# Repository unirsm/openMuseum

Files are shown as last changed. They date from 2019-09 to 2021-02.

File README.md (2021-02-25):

# openMuseum

## 1.0 Il progetto

### 1.1 Descrizione generale del progetto

Il Progetto di ricerca triennale “Nuovi sistemi integrativi per la fruizione del percorso espositivo della Casa Museo“ ha coinvolto in un programma di progettazione partecipata un gruppo di ricerca dell’area Exhibit e Interaction Design dell’Università delgi Studi della Repubblica di San Marino e le otto Istituzioni del Coordinamento delle Case Museo dei Poeti e degli Scrittori di Romagna (Protocollo di intesa sottoscritto dall’Università e dal Comune di Forlì, in qualità di Comune capofila del Coordinamento delle Case Museo dei Poeti e degli Scrittori di Romagna in data 18 luglio 2017).

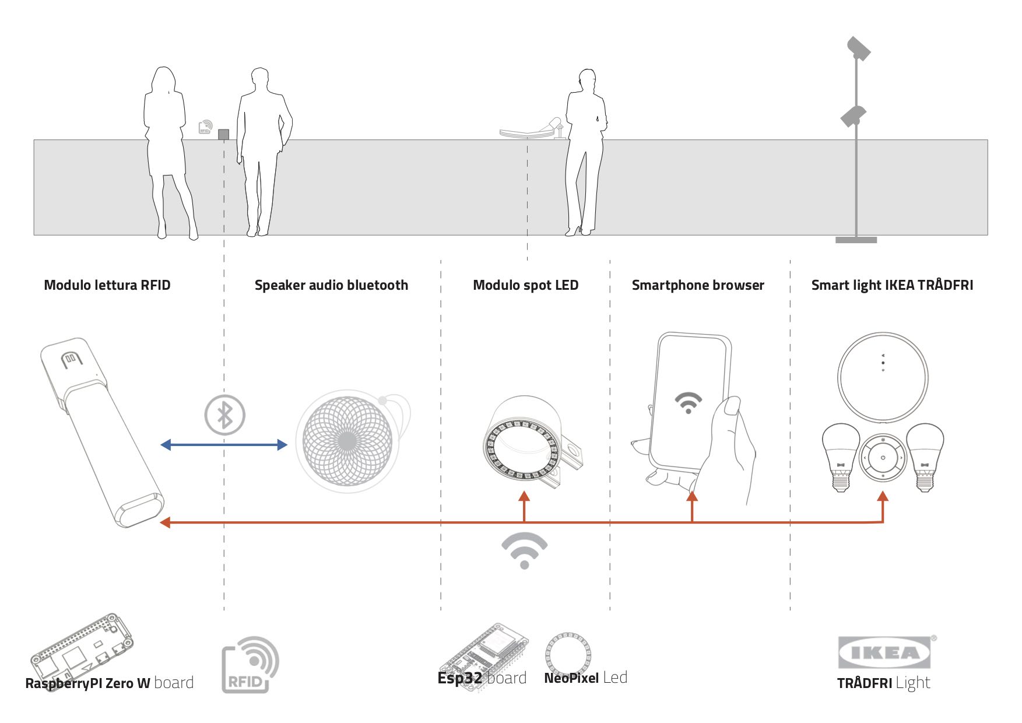
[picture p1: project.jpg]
Schema del progetto del sistema interattivo


### 1.2	Componenti hardware progettati

- [Reader RFID](reader/)
- [Spot Light neopixel](spotNeopixel/)
- [Server](server/)

### 1.3 Gruppo di lavoro progetto

Alessandra Bosco, Elena La Maida, Emanuele Lumini, Mirco Piccin e Michele Zannoni

## 2.0 Analisi preliminare e presupposti di progetto

### 2.1 Contesto

 - Case museo eterogenee con tipologie molto diverse di percorsi
   espositivi.
- Spazi liberi vuoti o stanze arredate.

### 2.2 Vincoli delle case museo

Necessità di un intervento non invasivo
- Impossibilità di fare interventi strutturali in diverse sale che alterino l’allestimento storico
- Allaccio alla rete elettrica molto problematico e troppo invasivo per alcuni contesti espositivi
- Non caricare dal punto di vista elettrico le strutture espositive
- Necessità dell’uso di una batteria e di un processo di ricarica semplice
- Sistema di ricarica della batteria certificato
- Personale eterogeneo e non preparato che può essere formato
- Problemi di connessione delle case
- Costo molto basso dell’oggetto interattivo
- Facilità e flessibilità d’uso

### 2.3	Presupposti

- Evitare l’inserimento di elementi estranei alle case museo evitando schermi e sistemi visivi permanenti
- Sviluppo di un sistema aperto e implementabile dagli operatori
- Dimensione contenuta degli oggetti
- Visibilità degli oggetti

### 2.4	Obiettivi principali

Gestione della presenza del visitatore nello spazio e attivazione di processi di interazione con contenuti audio e video.
- Permettere la contestualizzazione di un audio narrativo localizzato attivabile da un visitatore o da una guida.
- Gestire luci all’interno dello spazio per sottolineare singoli elementi.
- Sviluppare un progetto aperto e opensource che gli operatori delle case museo possano gestire in autonomia e modificare in futuro.
- Attivazione di contenuti specifici su smartphone in relazione alla prossimità.
- Piattaforma online per la gestione dei sistemi interattivi delle case
- Raccolta da remoto dei dati delle visite
- Strumenti di analisi dei dati dei visitatori all’interno delle case museo.
- Gestione degli elementi interattivi da remoto
- Gestione dinamica di un videoproiettore connesso alla rete elettrica. Struttura permanente da sviluppare in via prototipale ma non applicabile al budget del progetto.
- Gestione del mapping in spazi vuoti in maniera dinamica.

## 3.0 License

Attribution-NonCommercial 4.0 International (CC BY-NC 4.0)
the  [license](https://creativecommons.org/licenses/by-nc/4.0/legalcode). [Disclaimer](https://creativecommons.org/licenses/by-nc/4.0/#).

Share — copy and redistribute the material in any medium or format
Adapt — remix, transform, and build upon the material
The licensor cannot revoke these freedoms as long as you follow the license terms.
Authors: Alessandra Bosco, Elena La Maida, Emanuele Lumini, Mirco Piccin e Michele Zannoni

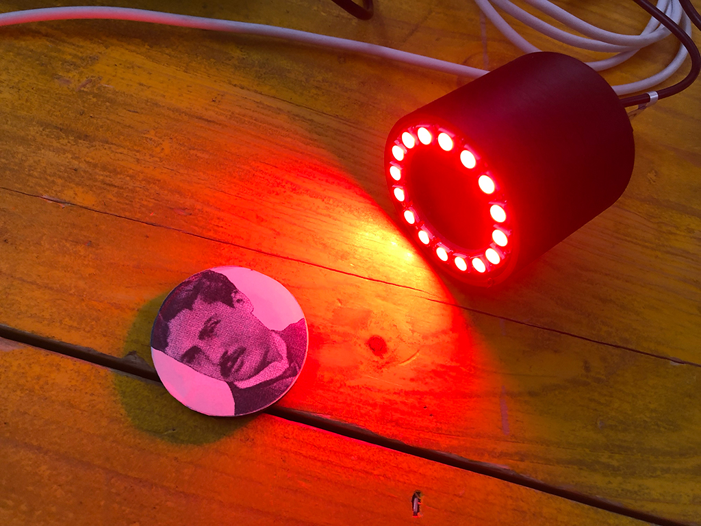
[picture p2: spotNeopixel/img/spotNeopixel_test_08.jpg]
Spot Light neopixel Prototipo


Fig. 1 Lo spot realizzato per la sperimentazione

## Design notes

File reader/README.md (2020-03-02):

# Modulo lettore RFID portatile

Il lettore portatile funziona leggendo con  antenna  RC522 i tag RFID posizionati nello spazio espositivo. Il sistema è costituito da una Raspberry PI zero W con installato Node-Red e Mosquitto.
Il lettore può essere connesso a qualsiasi sistema di riproduzione audio Bluetooth (Speaker, Cuffie e sistemi di diffusione audio permanenti).

## Password e user delle ISO e del reader
La password di default dell'utente "pi" dell'ISO è "password"

La password di default di Node-Red dell'utente "admin" è "password"

La password di default del sistema di gestione dei contenuti multimediali dell'utente "admin" è "password"

[Download ISO 20190929 v.07a](https://www.dropbox.com/s/mdmm8pqs013waee/20190929_Iso_base_CCM.img.zip?dl=0)

[Last Node-Red flow](node-red/flows_casamuseorpi.json)

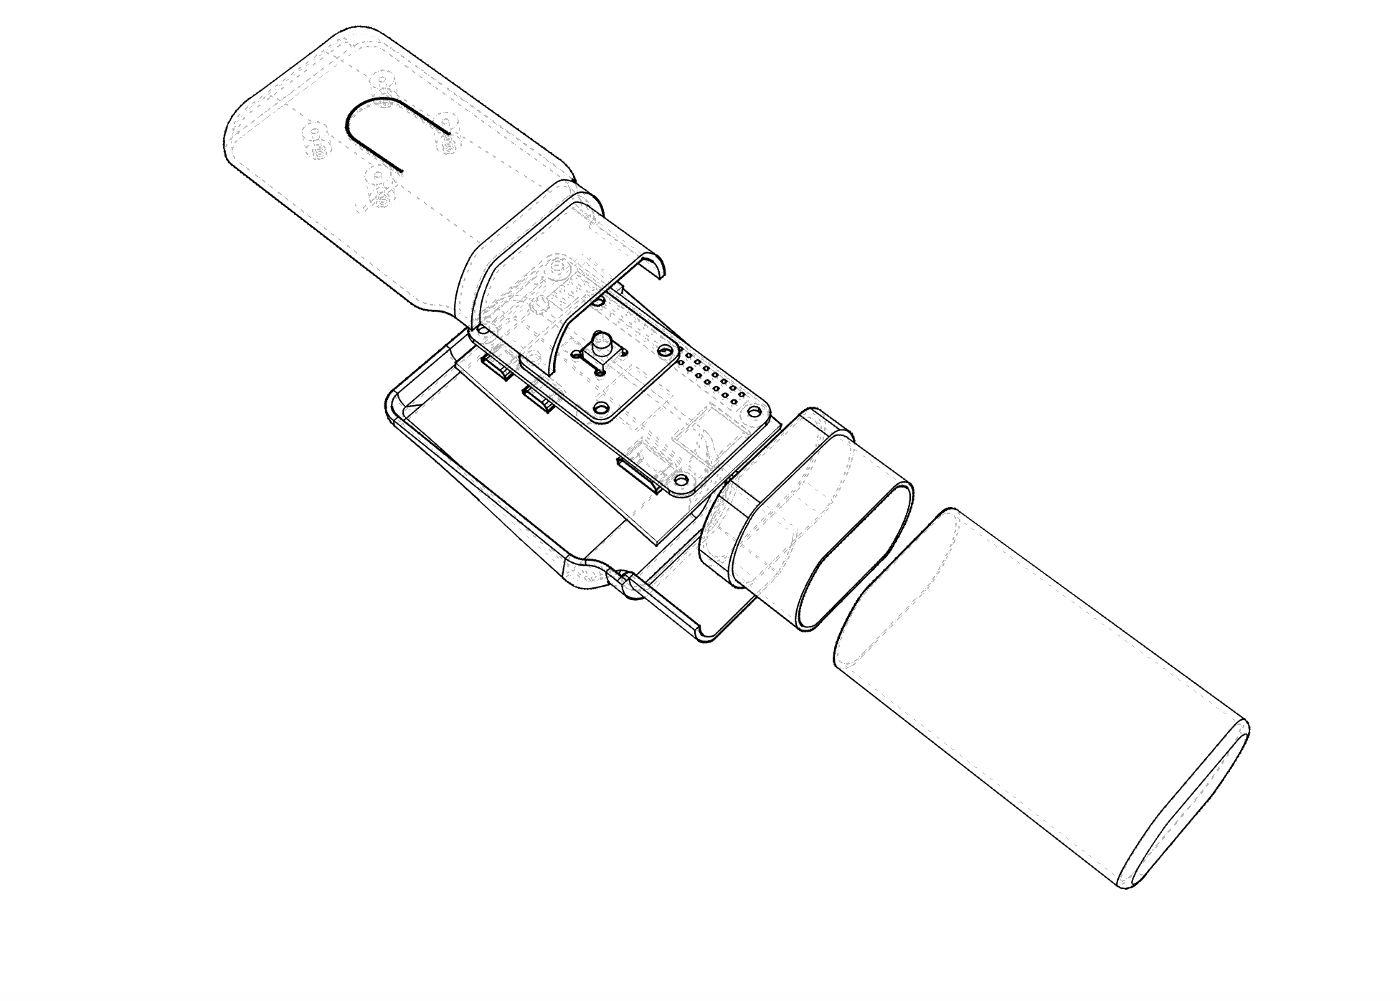
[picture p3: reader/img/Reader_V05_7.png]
Reader 3D printing model 5


## Procedura di aggiornamento

- 1	Caricamento del FLOW aggiornato
- 1.1	Collegarsi in SFTP al device
- 1.2	Caricare il file flows_casamuseorpi.json nella cartella /home/pi/.node-red/ (Attivare la visualizzazione dei file nascosti)
- 1.3	Caricare il vostro file logo.png nella cartella /home/pi/media/
- 1.4	Riavviare il device

## Dimensione componenti

- Raspberry PI zero W: 			32x68x6 mm

- antenna rfid RC522: 			39x60x6 mm
s
- powerbank: 				94x24x23 mm

- pulsante switch 			6x6x7 mm
- Bluetooth Speaker esterno

## Hardware

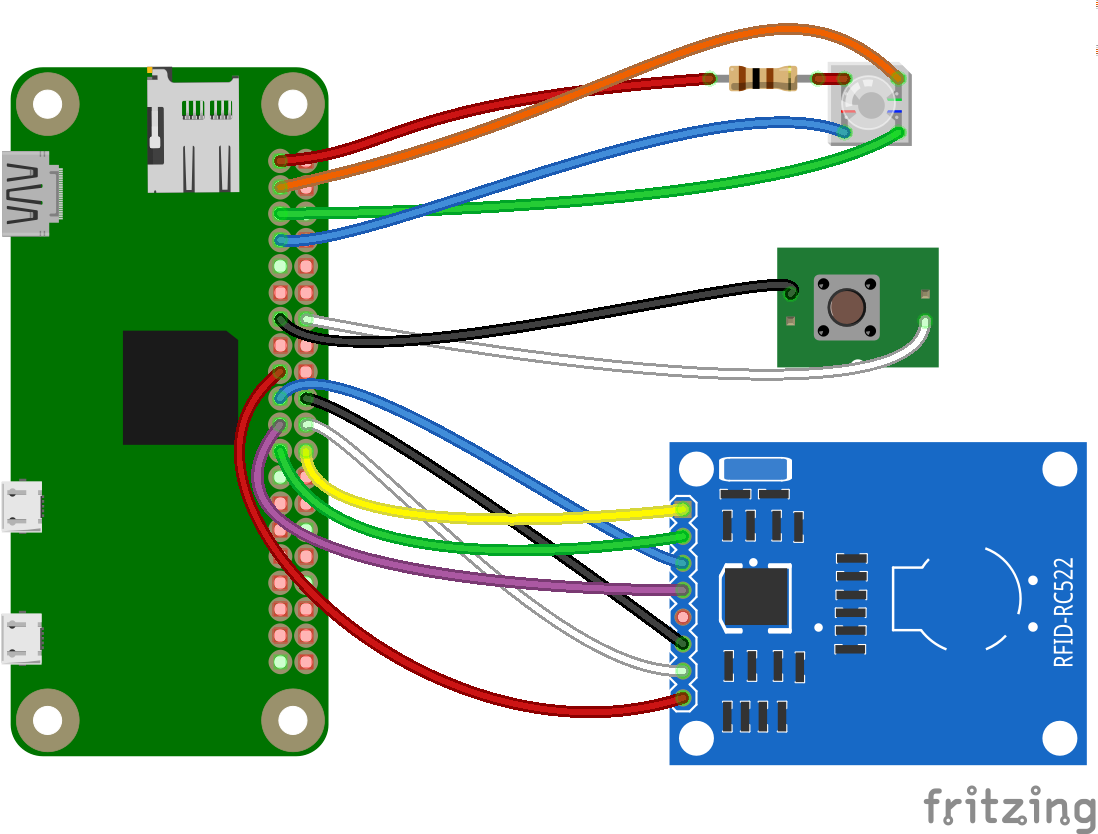
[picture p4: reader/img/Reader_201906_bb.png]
Reader hardware connections

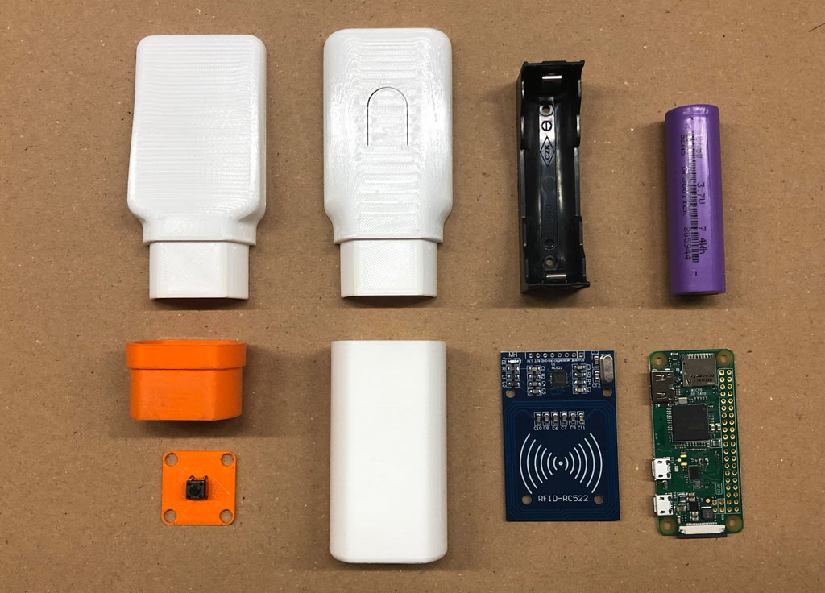
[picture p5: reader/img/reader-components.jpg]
Hardware components


## The 3d printing model

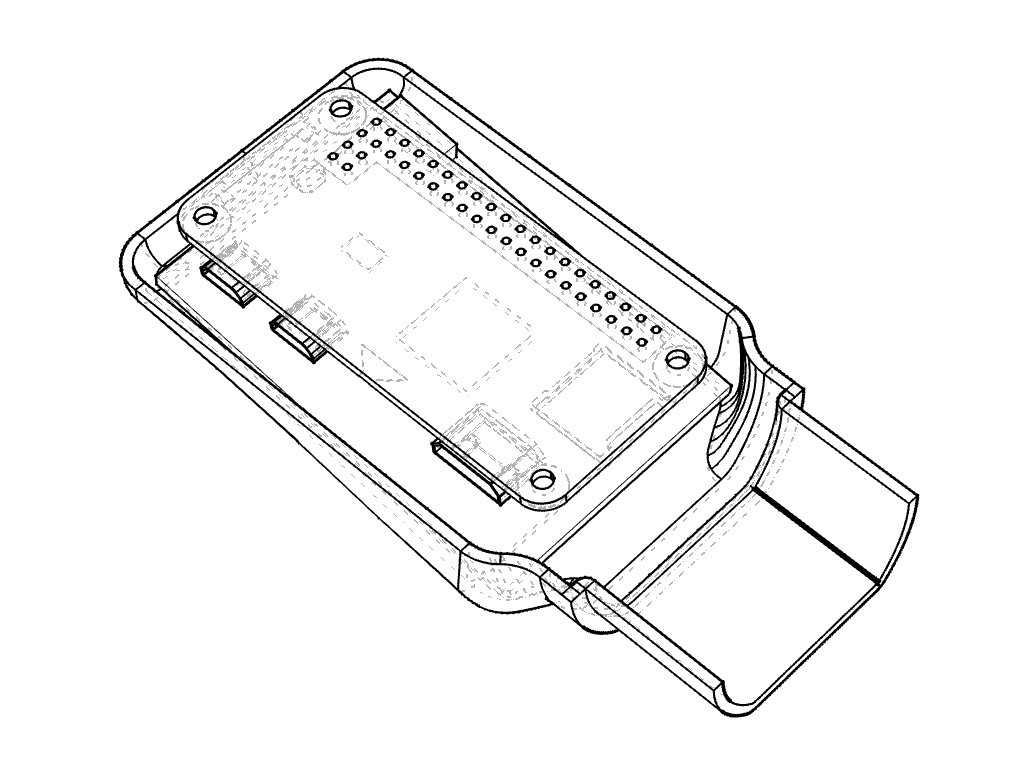
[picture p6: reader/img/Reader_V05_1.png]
Reader picture 1 model 5

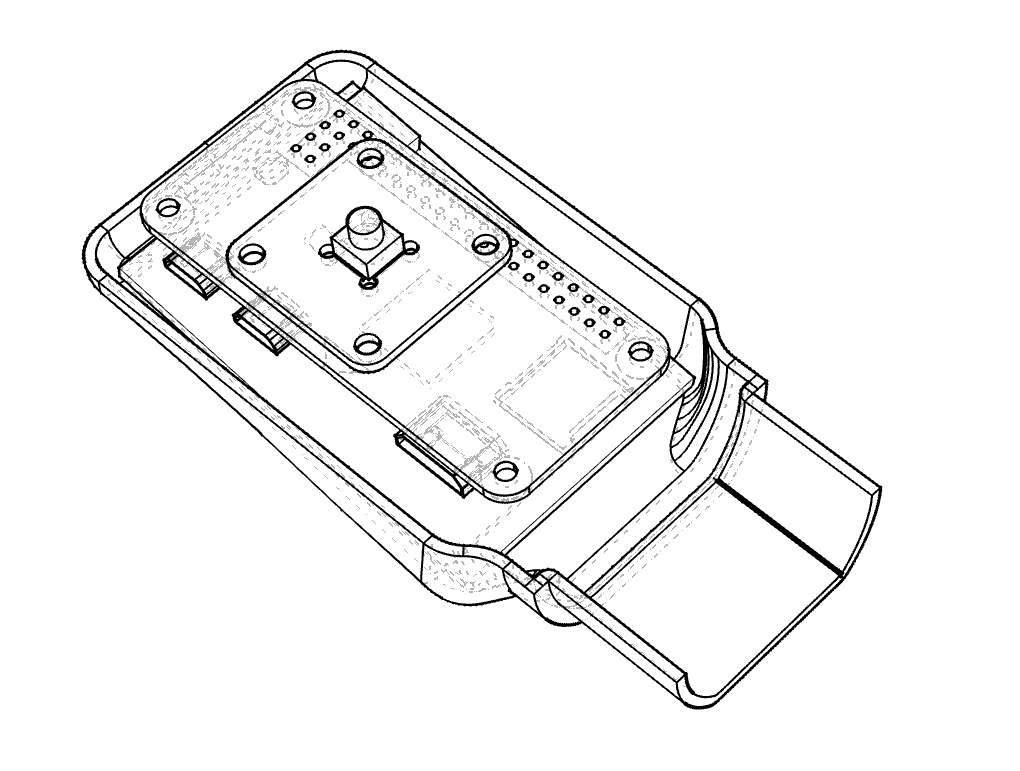
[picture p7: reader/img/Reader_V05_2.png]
Reader picture 2 model 5

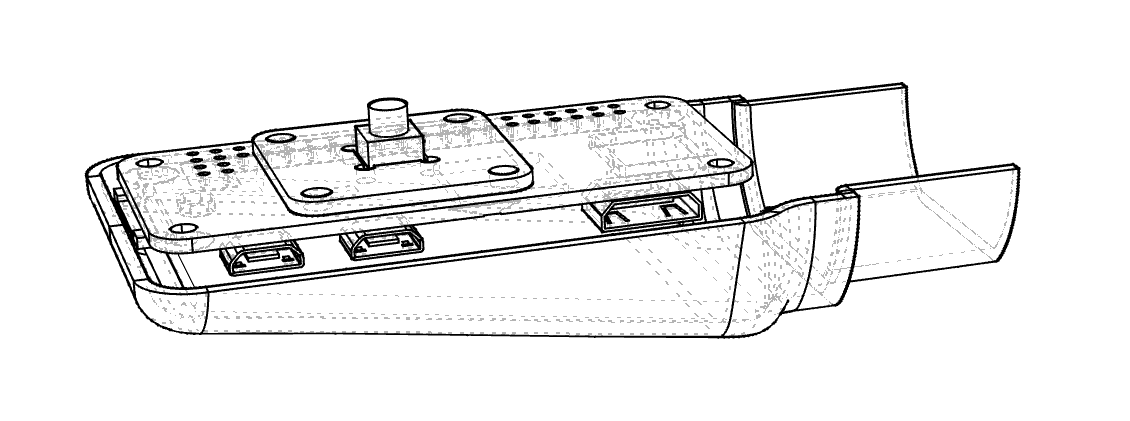
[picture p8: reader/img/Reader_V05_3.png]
Reader picture 3 model 5

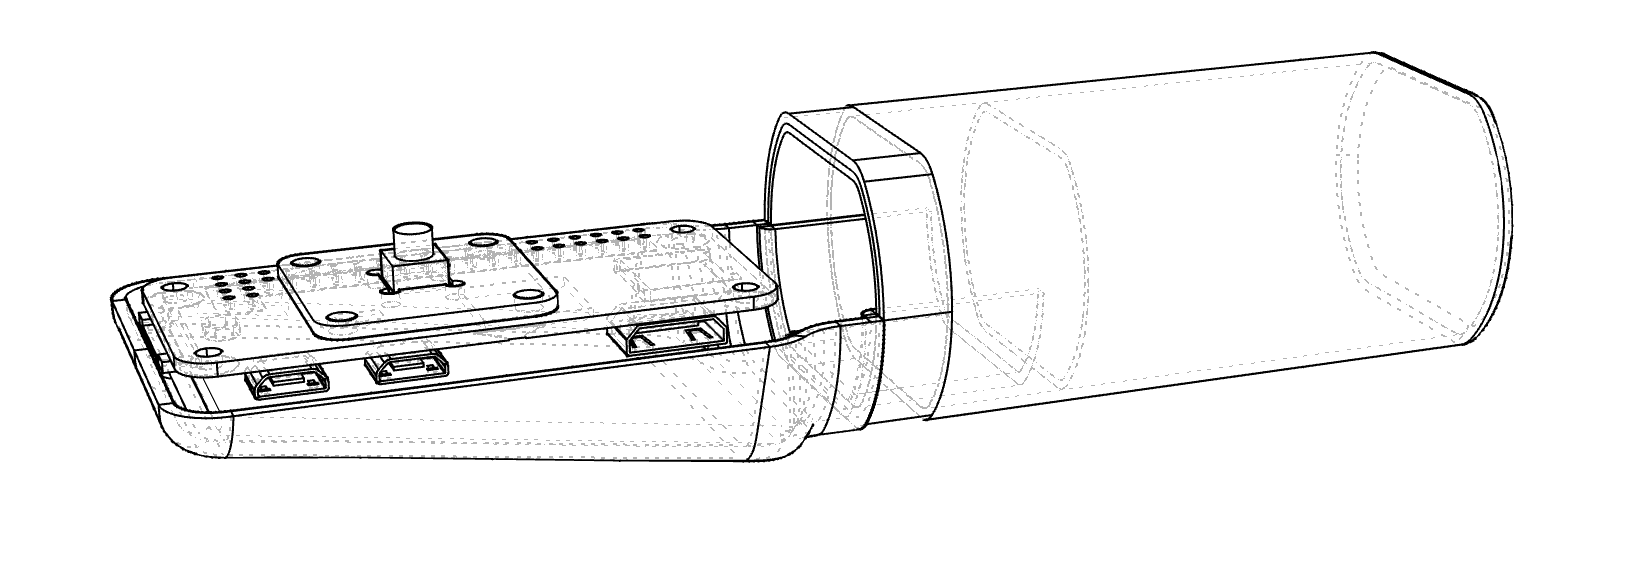
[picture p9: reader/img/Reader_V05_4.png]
Reader picture 4 model 5

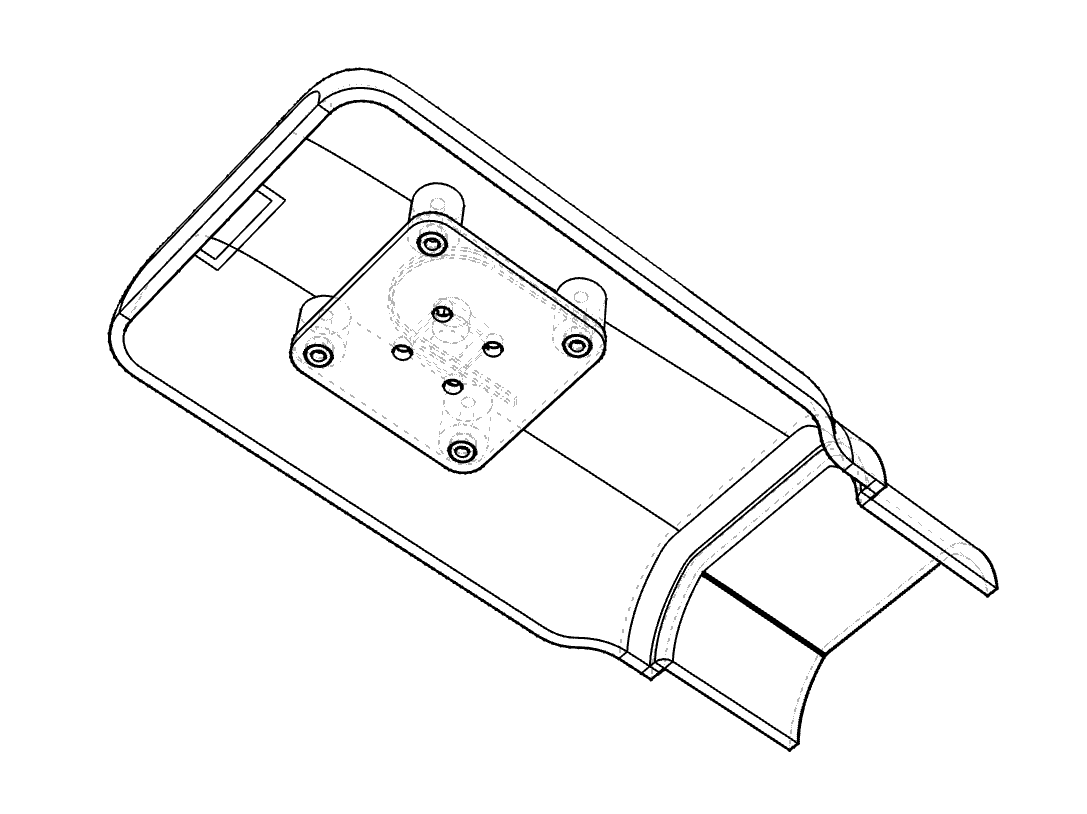
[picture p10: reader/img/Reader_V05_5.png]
Reader picture 5 model 5

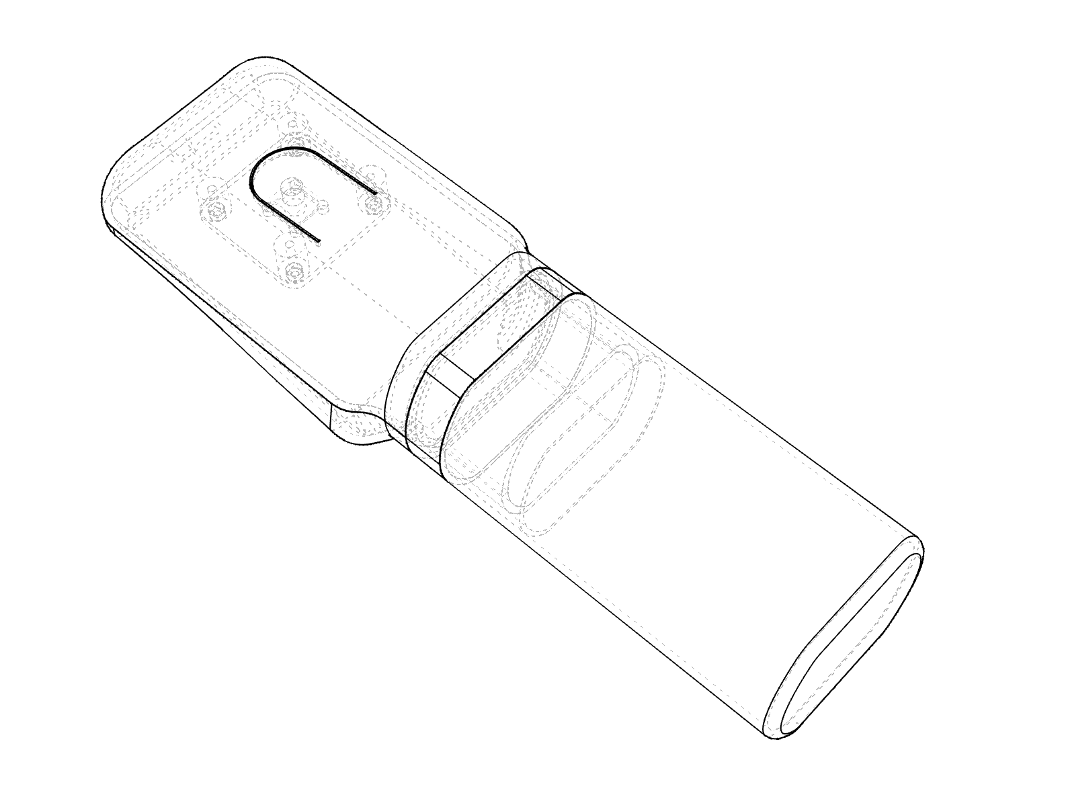
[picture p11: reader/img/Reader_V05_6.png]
Reader picture 6 model 5


## The prototypes

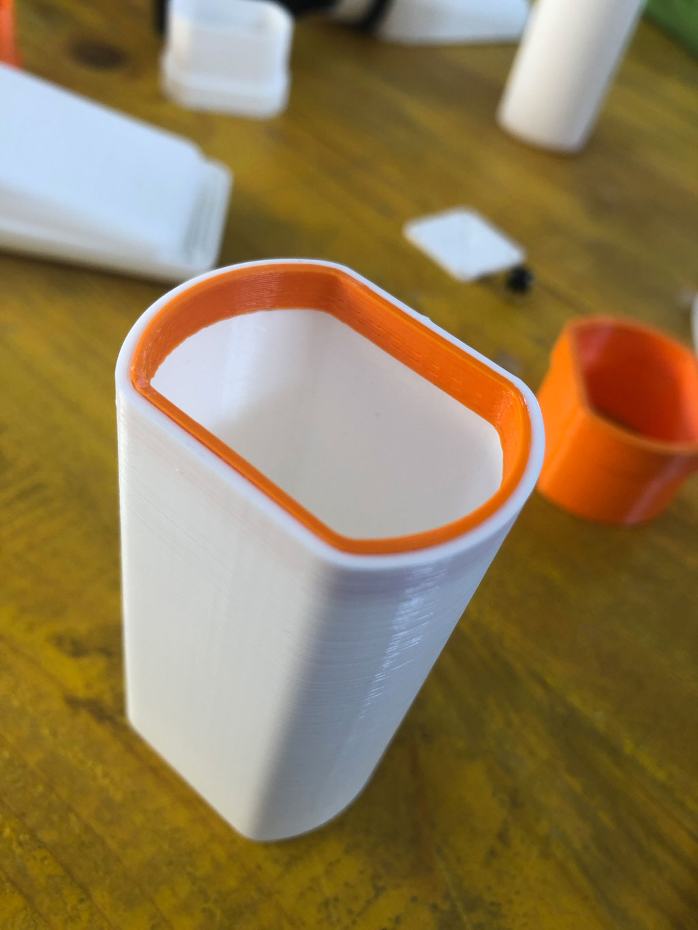
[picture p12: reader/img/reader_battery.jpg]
Reader picture 6 model 5

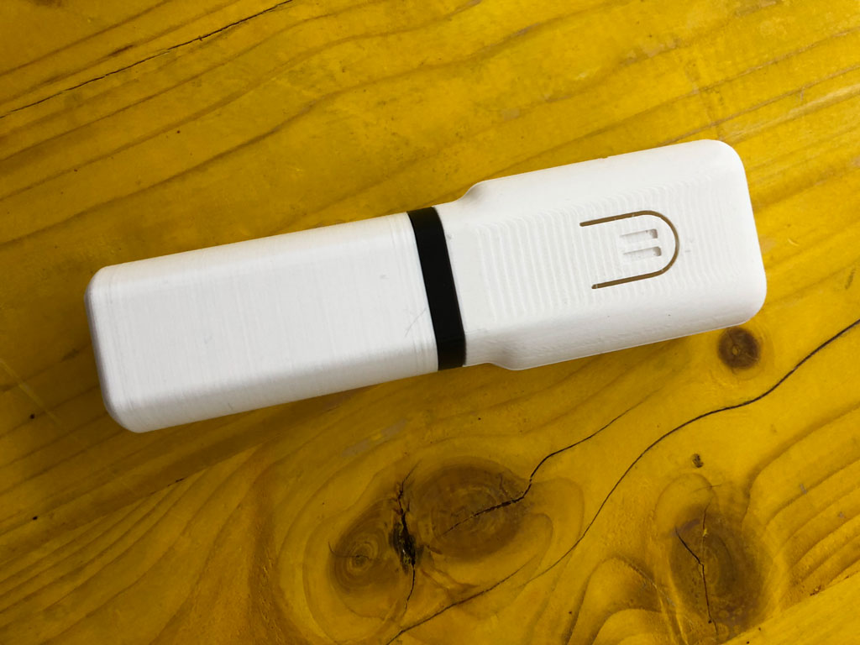
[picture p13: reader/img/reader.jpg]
Reader picture 6 model 5

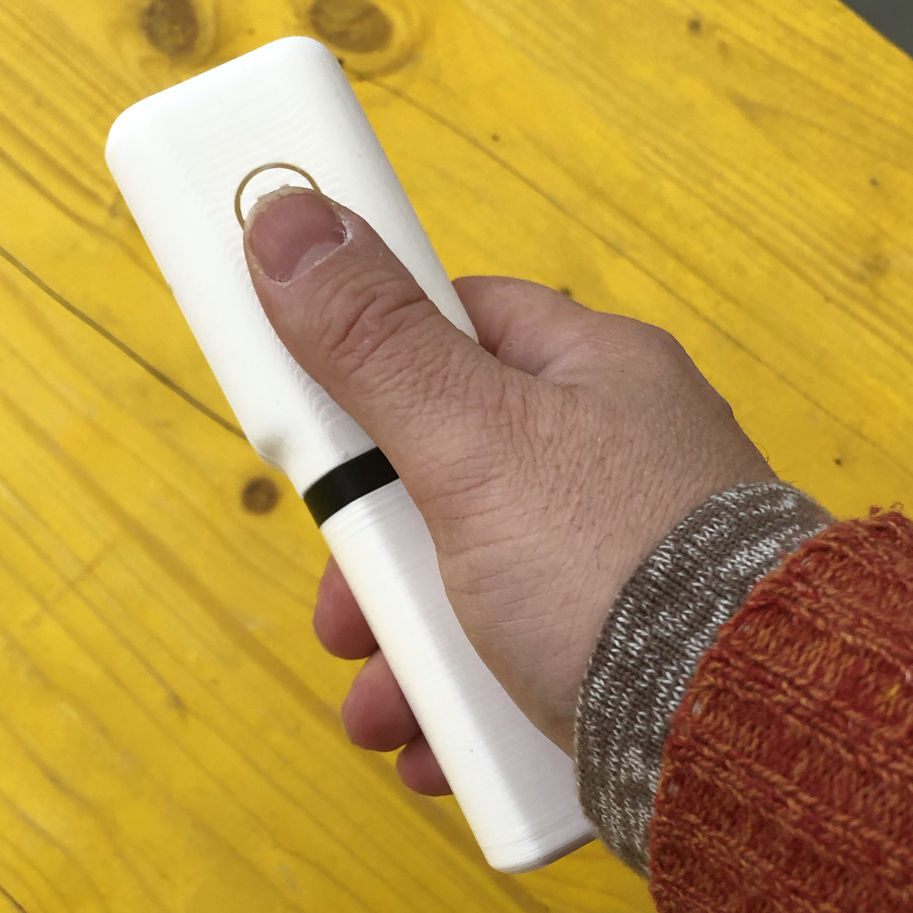
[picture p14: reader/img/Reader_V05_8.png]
Reader picture 6 model 5

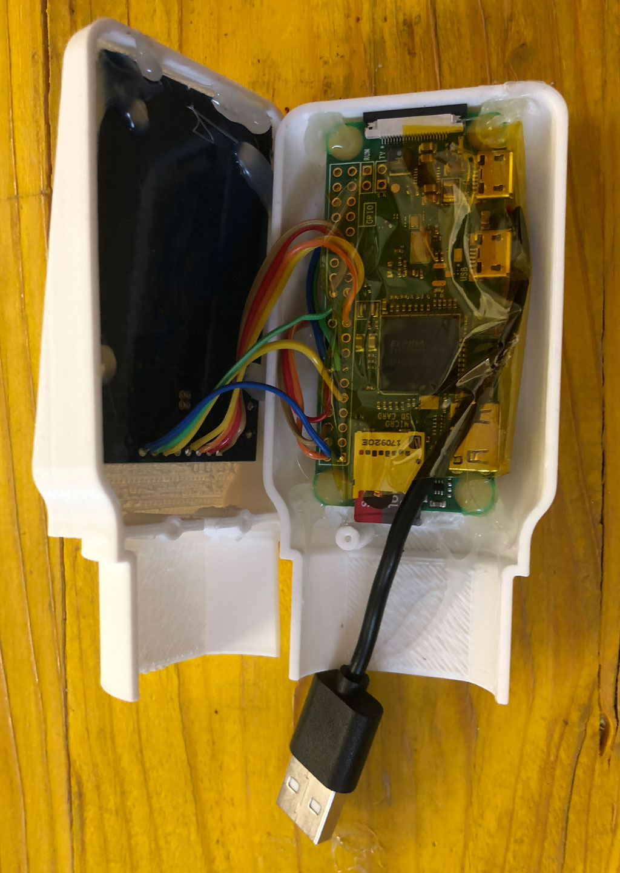
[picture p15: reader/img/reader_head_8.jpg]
Reader picture 6 model 5


## License

Attribution-NonCommercial 4.0 International (CC BY-NC 4.0)
the  [license](https://creativecommons.org/licenses/by-nc/4.0/legalcode). [Disclaimer](https://creativecommons.org/licenses/by-nc/4.0/#).

Share — copy and redistribute the material in any medium or format
Adapt — remix, transform, and build upon the material
The licensor cannot revoke these freedoms as long as you follow the license terms.
Authors: Alessandra Bosco, Elena La Maida, Emanuele Lumini, Mirco Piccin e Michele Zannoni

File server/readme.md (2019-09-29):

# Modulo Server

Il server ha due componenti: una sviluppata in PHP e MYSQL che può risiedere anche su un provider online e una locale installata su una Raspberry PI 3 B+ sviluppata in Node-RED per migliorare lo streaming video e la gestione dei sistemi domotici.

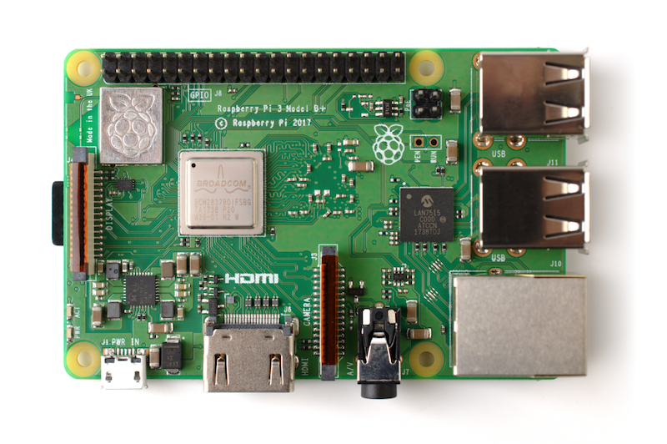
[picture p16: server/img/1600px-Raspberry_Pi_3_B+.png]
Raspberry PI 3 B+ photo by Gareth Halfacree


## Password e user delle ISO e del server
La password di default dell'utente "pi" dell'ISO è "password"

La password di default di Node-Red dell'utente "admin" è "password"

La password di default del sistema di gestione dei contenuti multimediali dell'utente "admin" è "password"

- [Download ISO 20190929 v.07a](https://www.dropbox.com/s/mdmm8pqs013waee/20190929_Iso_base_CCM.img.zip?dl=0)
- [Last Node-Red flow](node-red/flows_casamuseorpi.json)

## Hardware

- Raspberry PI 3 B+

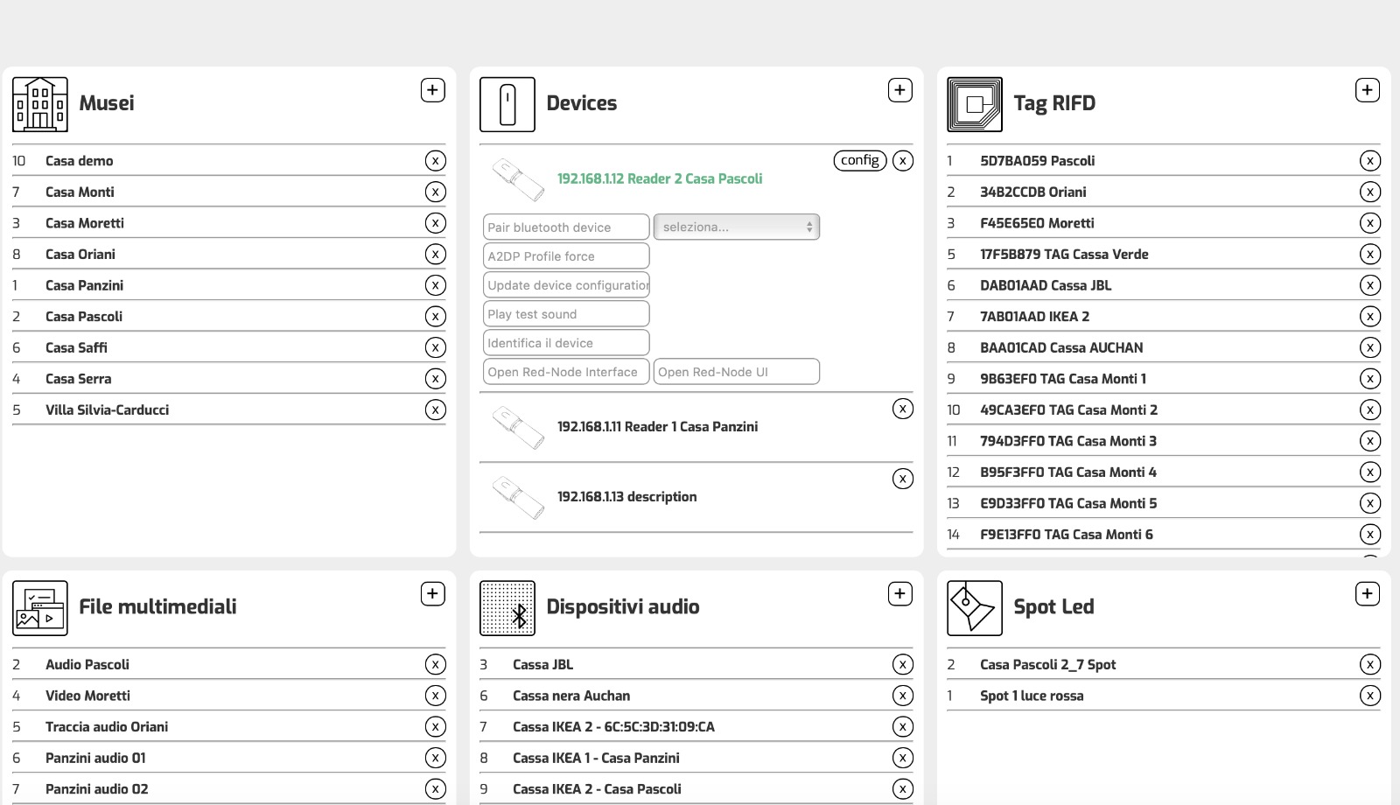
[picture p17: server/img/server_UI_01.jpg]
Server Web UI

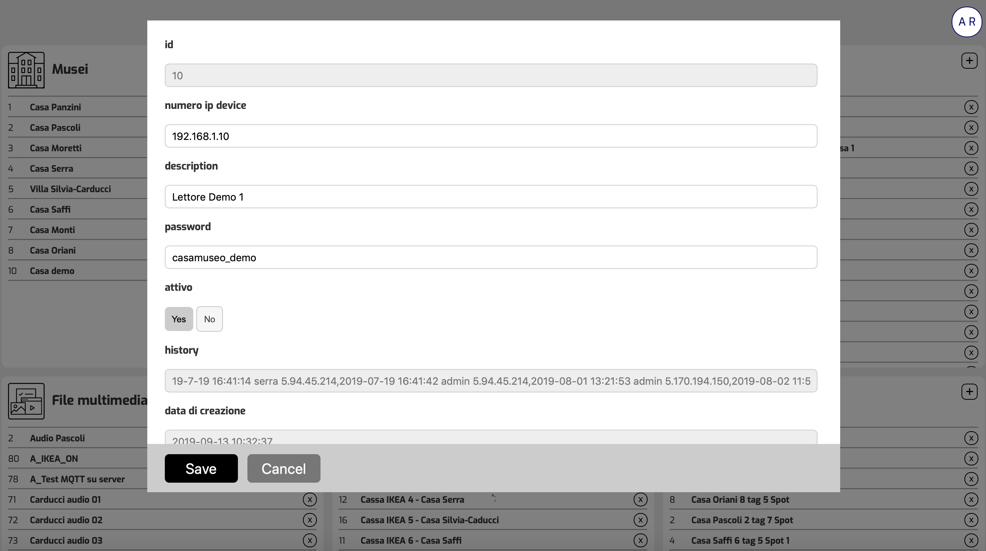
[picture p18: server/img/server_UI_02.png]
Server Web UI

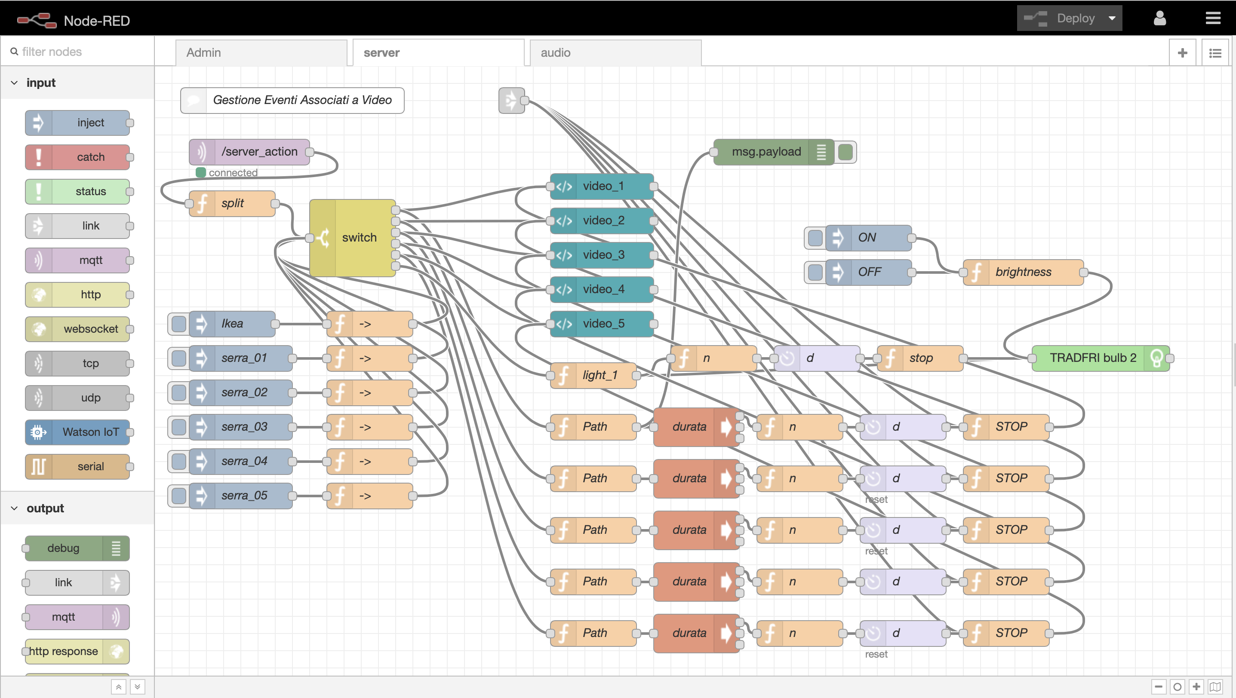
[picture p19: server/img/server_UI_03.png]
Server Web UI


## License

Attribution-NonCommercial 4.0 International (CC BY-NC 4.0)
the  [license](https://creativecommons.org/licenses/by-nc/4.0/legalcode). [Disclaimer](https://creativecommons.org/licenses/by-nc/4.0/#).

Share — copy and redistribute the material in any medium or format
Adapt — remix, transform, and build upon the material
The licensor cannot revoke these freedoms as long as you follow the license terms.
Author: Michele Zannoni

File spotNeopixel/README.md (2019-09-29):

# Modulo Spot Light Neopixel

Alimentato con un powerbank è pensato per essere inserito in contesti privi di rete elettrica.

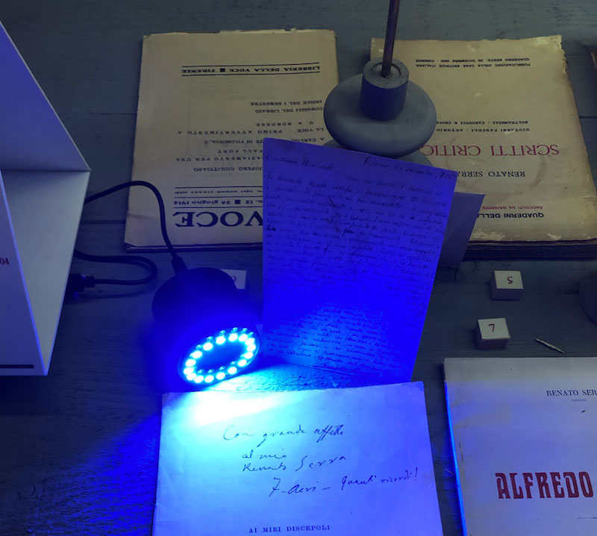
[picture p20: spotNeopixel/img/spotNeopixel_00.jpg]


## Hardware

- Wemos D1 R2 & mini
- Adafruit NeoPixel

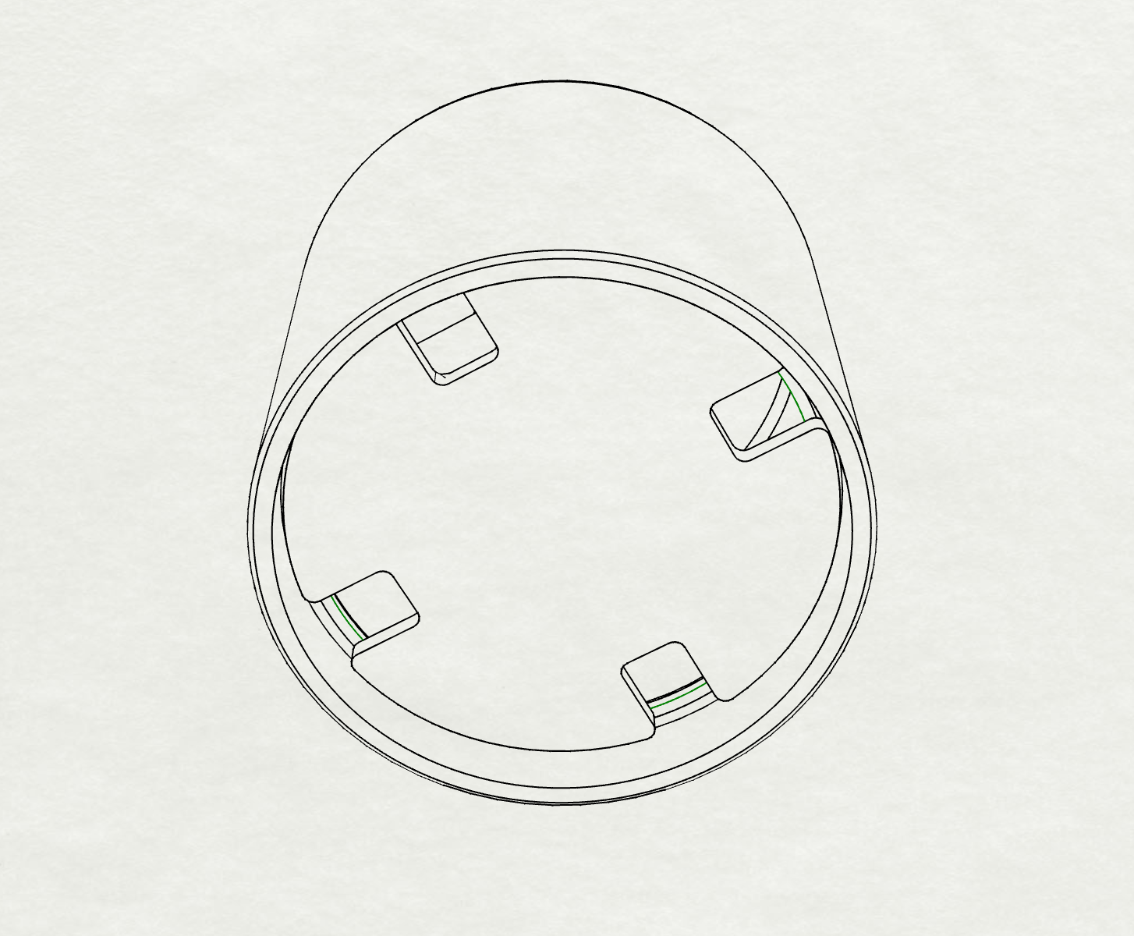
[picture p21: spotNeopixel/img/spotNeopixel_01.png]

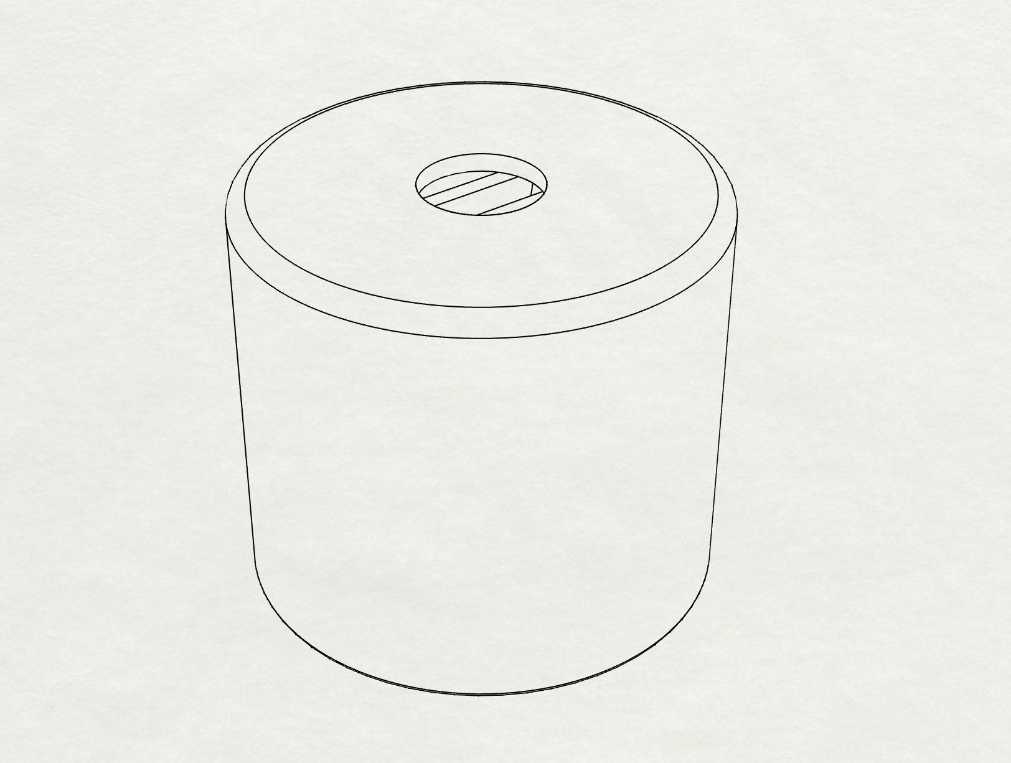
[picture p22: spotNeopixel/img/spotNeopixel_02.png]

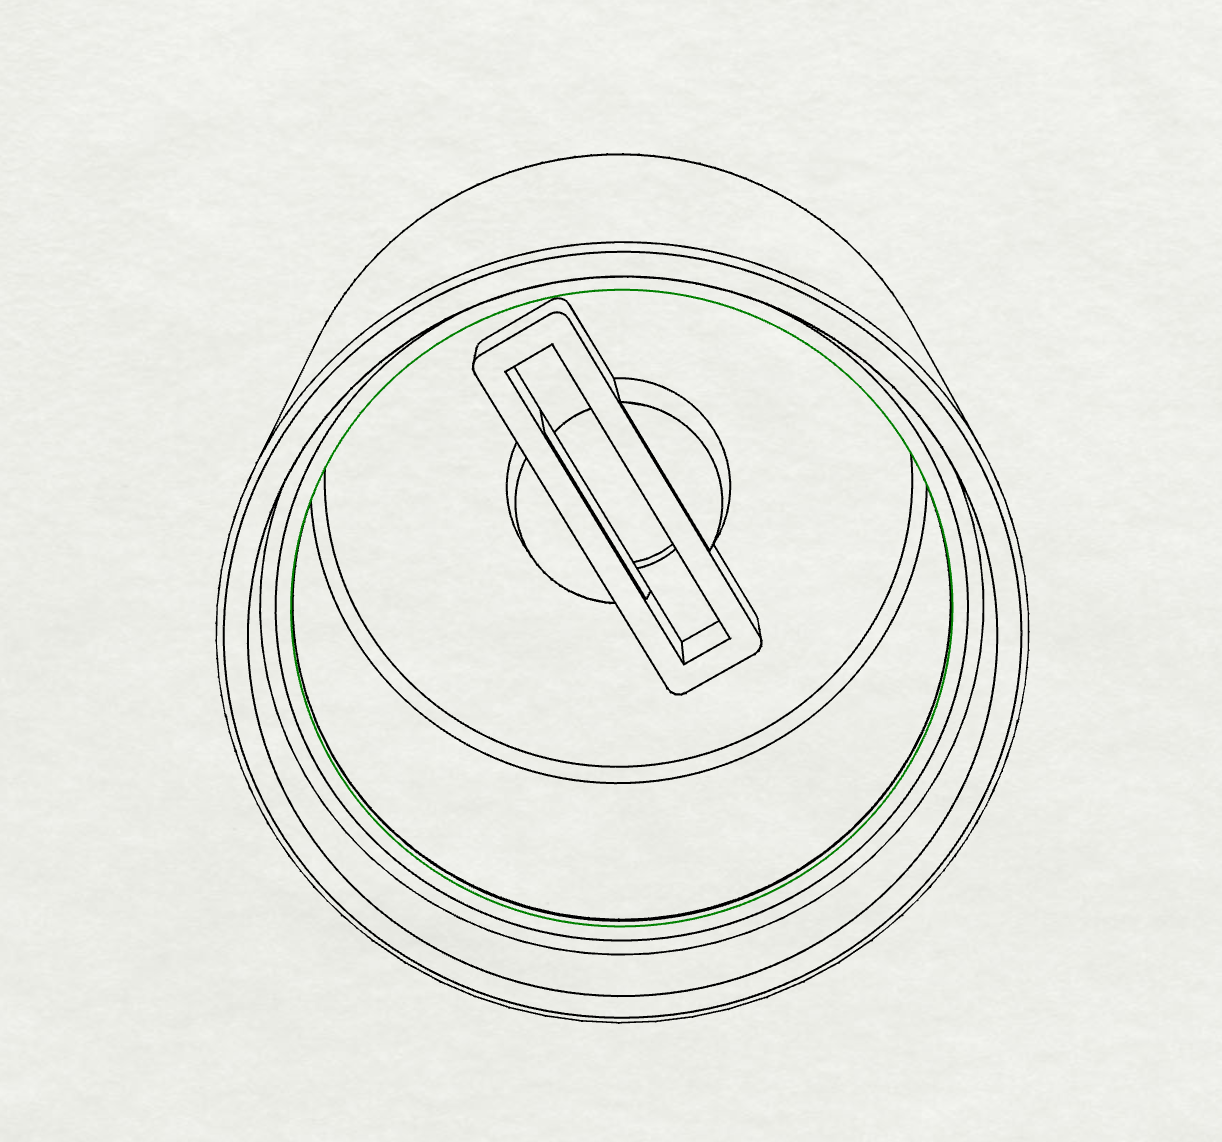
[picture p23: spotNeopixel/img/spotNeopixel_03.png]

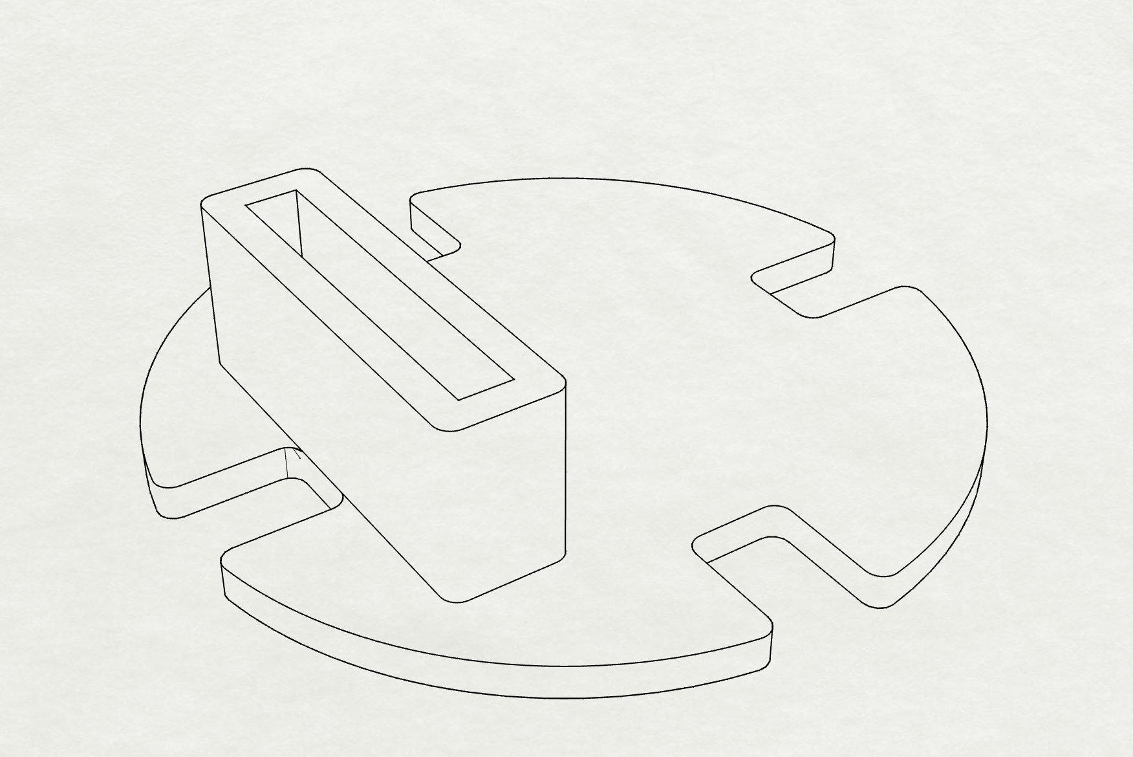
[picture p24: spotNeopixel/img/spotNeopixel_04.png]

Il prototipo
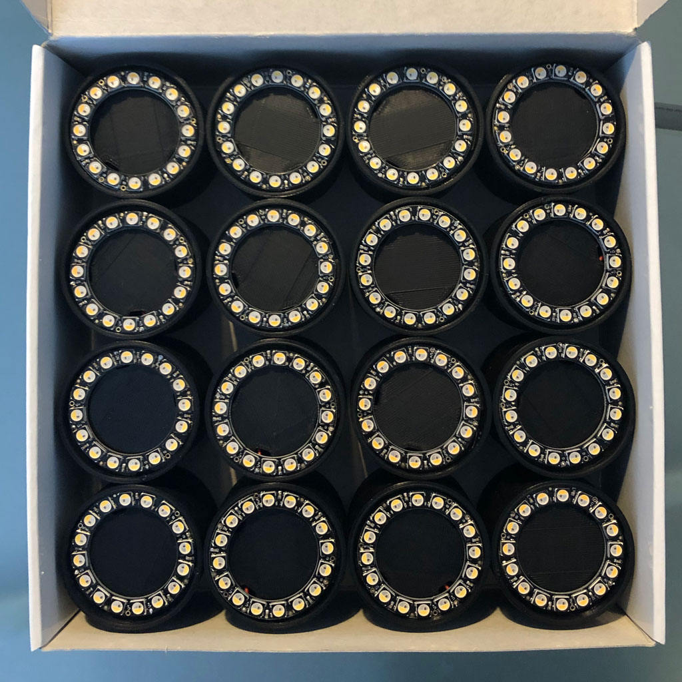
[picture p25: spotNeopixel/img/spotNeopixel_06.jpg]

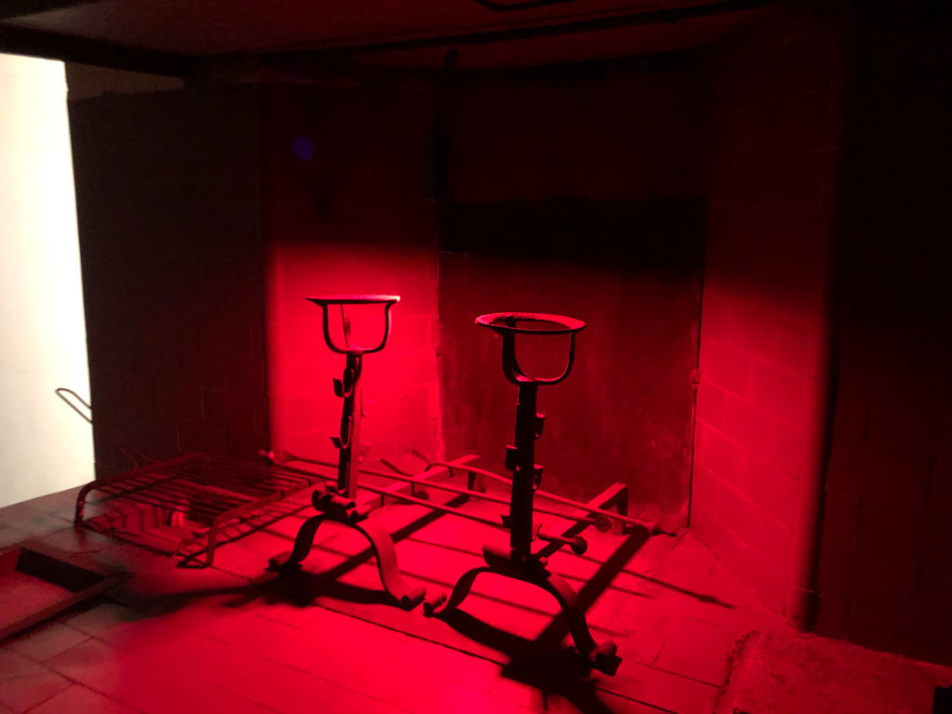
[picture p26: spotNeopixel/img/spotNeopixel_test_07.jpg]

Il prototipo

## License

Attribution-NonCommercial 4.0 International (CC BY-NC 4.0)
the  [license](https://creativecommons.org/licenses/by-nc/4.0/legalcode). [Disclaimer](https://creativecommons.org/licenses/by-nc/4.0/#).

Share — copy and redistribute the material in any medium or format
Adapt — remix, transform, and build upon the material
The licensor cannot revoke these freedoms as long as you follow the license terms.
Authors: Mirco Piccin e Michele Zannoni

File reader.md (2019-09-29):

# Modulo lettore 1 RFID portatile

Il lettore portatile funziona leggendo con  antenna  RC522 i tag RFID posizionati nello spazio espositivo. Il sistema è costituito da una Raspberry PI zero W con installato Node-Red e Mosquitto.
Il lettore può essere connesso a qualsiasi sistema di riproduzione audio Bluetooth (Speaker, Cuffie e sistemi di diffusione permanenti).

Reader 3D printing model 5

## Dimensione componenti

- Raspberry PI zero W: 			32x68x6 mm

- antenna rfid RC522: 			39x60x6 mm
s
- powerbank: 				94x24x23 mm

- pulsante switch 			6x6x7 mm
- Bluetooth Speaker esterno

## Hardware

Reader hardware connections

## The 3d printing model

# Modulo lettore 1 RFID portatile

Il lettore portatile funziona leggendo con  antenna  RC522 i tag RFID posizionati nello spazio espositivo. Il sistema è costituito da una Raspberry PI zero W con installato Node-Red e Mosquitto.
Il lettore può essere connesso a qualsiasi sistema di riproduzione audio Bluetooth (Speaker, Cuffie e sistemi di diffusione permanenti).

## Dimensione componenti

- Raspberry PI zero W: 			32x68x6 mm

- antenna rfid RC522: 			39x60x6 mm
s
- powerbank: 				94x24x23 mm

- pulsante switch 			6x6x7 mm
- Bluetooth Speaker esterno

## Hardware

Reader picture 1 model 5
Reader picture 2 model 5
Reader picture 3 model 5
Reader picture 4 model 5
Reader picture 5 model 5
Reader picture 6 model 5

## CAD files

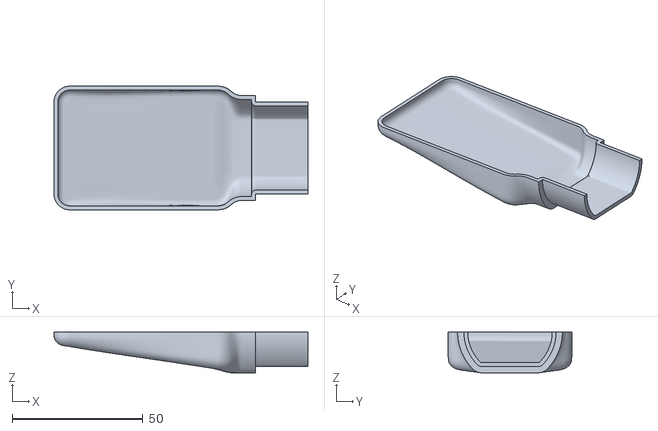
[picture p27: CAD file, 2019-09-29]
reader/stl/Reader_bottom_head_05d.stl
97.0 x 47.3 x 15.6

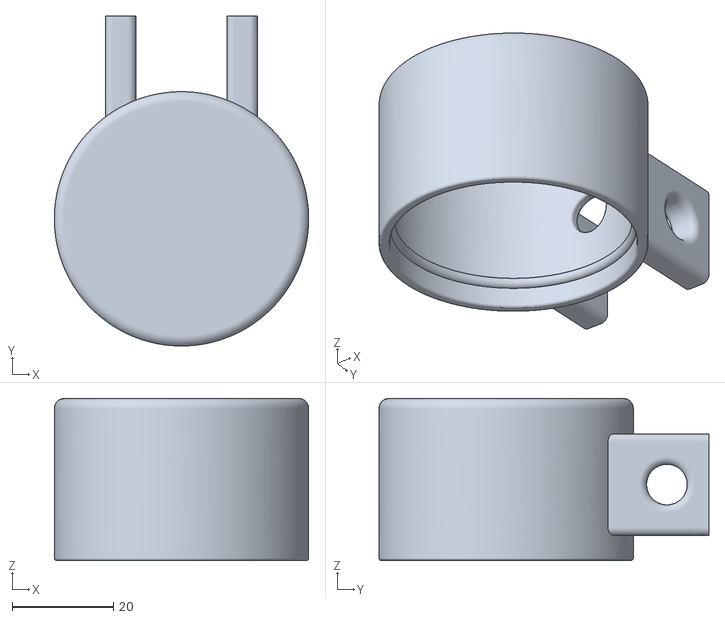
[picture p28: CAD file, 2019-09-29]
spotNeopixel/stl/neopixel_01.stl
50.2 x 65.1 x 32.0

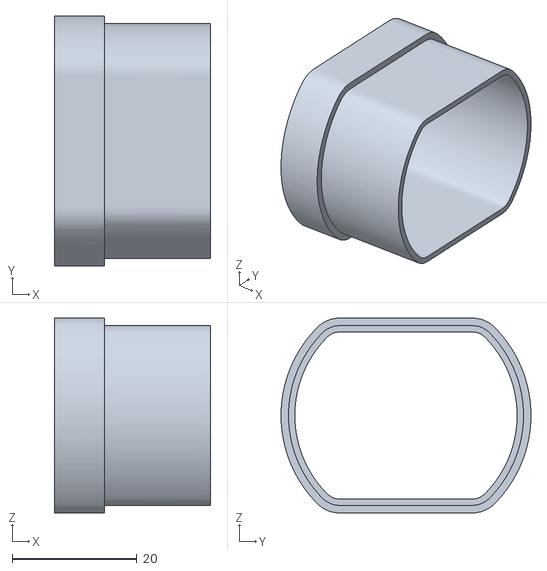
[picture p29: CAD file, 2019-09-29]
reader/stl/Reader_ring_05d.stl
25.0 x 40.0 x 31.2

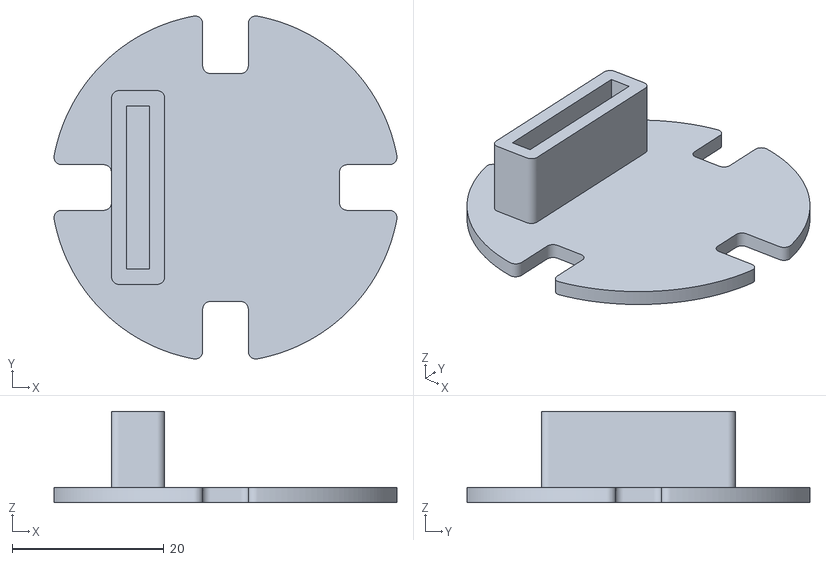
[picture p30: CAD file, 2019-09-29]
spotNeopixel/stl/neopixel_02_supporto.stl
45.1 x 45.1 x 12.0

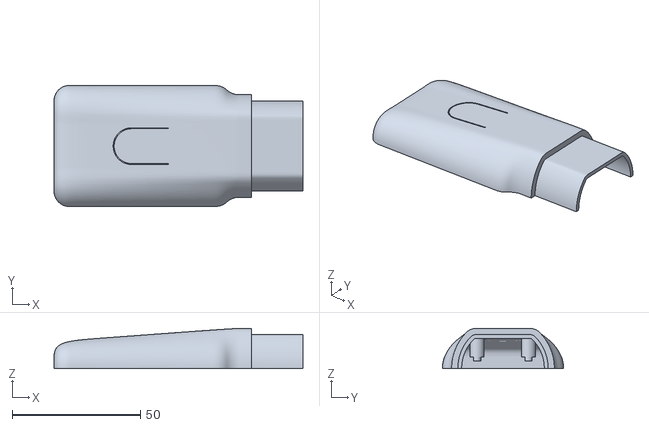
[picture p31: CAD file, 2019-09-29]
reader/stl/Reader_top_head_05d.stl
97.0 x 47.2 x 15.6

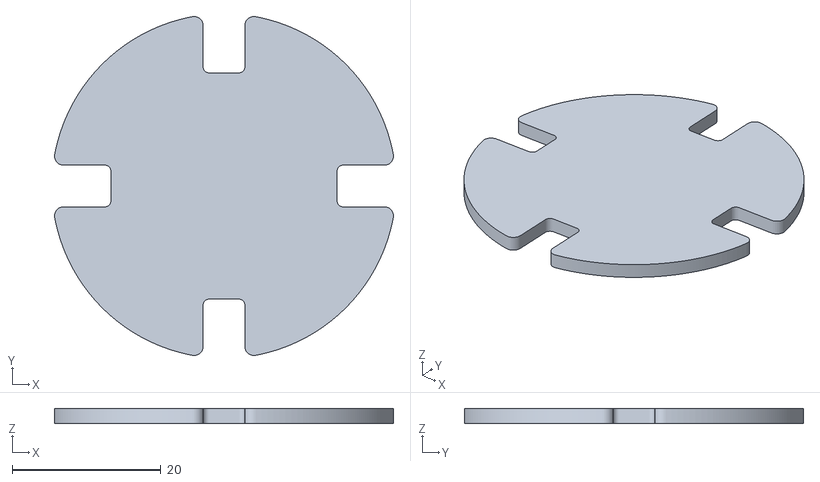
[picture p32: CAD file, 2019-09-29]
spotNeopixel/stl/neopixel_02_tappo.stl
45.5 x 45.5 x 2.00

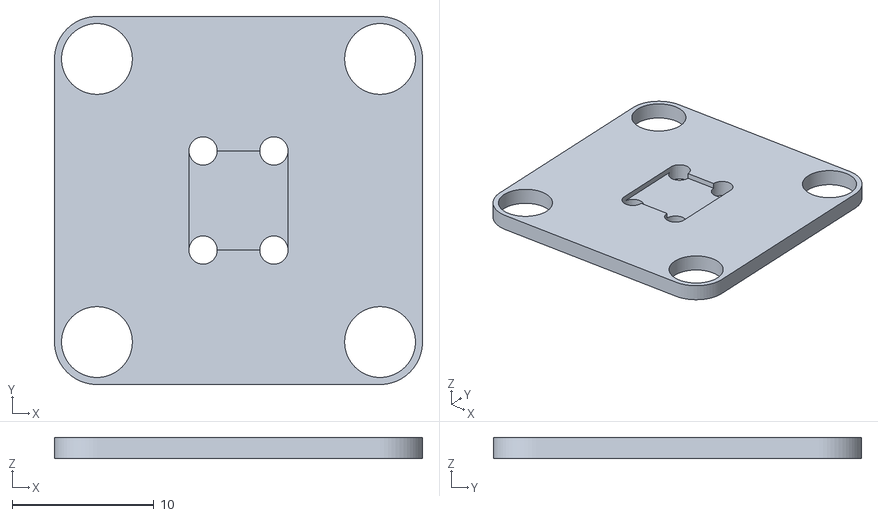
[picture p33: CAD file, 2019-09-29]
reader/stl/Reader_base_button_05a.stl
26.0 x 26.0 x 1.50

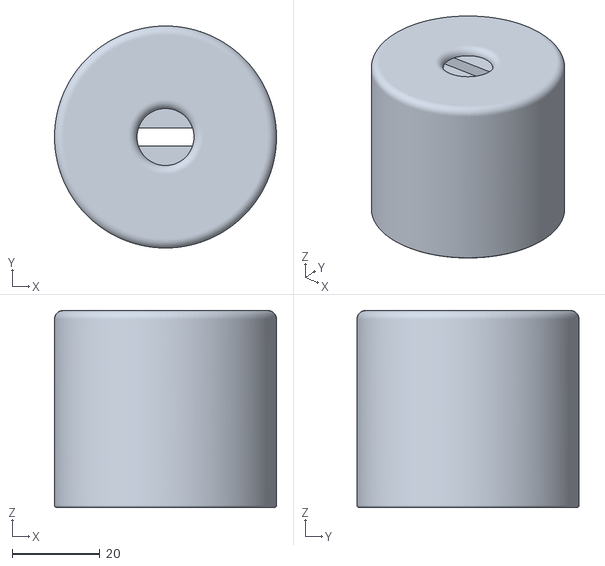
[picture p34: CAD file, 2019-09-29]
spotNeopixel/stl/neopixel_02_guscio.stl
50.7 x 50.7 x 45.0

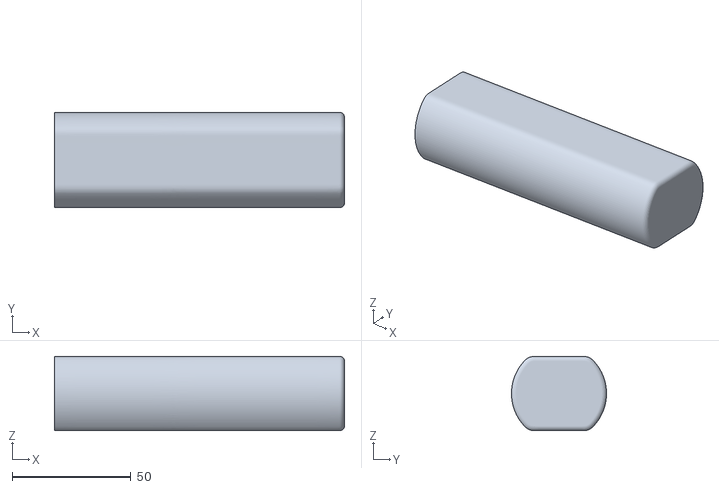
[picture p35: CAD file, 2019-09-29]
reader/stl/Reader_battery_05d.stl
122.1 x 40.0 x 31.2

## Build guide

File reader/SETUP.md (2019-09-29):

# Connessione rete wifi e contenuti interattivi

La configurazione della rete wifi avviene localmente inserendo nella partizione di boot nella memoria sd, un file chiamato: *basic_config.json*. Al primo avvio il sistema si connetterà alla rete leggendo i parametri indicati nel file.

### *File:  basic_config.json*

    [{
           "casamuseo_id": 2,
           "ssid": "nomerete",
           "password": "password",
           "server_remoto_configurazione": "http://lab.z14.it/giano"
           "ip_address": "192.168.189.55"
           "gateway": "192.168.189.1"
           "dns": "192.168.189.1",
	       "password_reader": "password_operativa"
    }]

Queste informazioni sono sufficienti a stabilire la connessione del lettore alla rete locale, e a permettere allo stesso di raggiungere il server (sia esso locale o remoto) da cui scaricare tutte le configurazioni di TAG, contenuti, interazioni. La password_reader va inserita uguale nel record del sistema online e permetterà di interagire con il disposto dalla piattaforma web. La voce "casamuseo_id" indica il riferimento della tabella online da cui recuperare i json secondo il seguente schema.

### Configurazione Remota

La configurazione remota avviene attraverso WUI: una parte di tale configurazione viene eseguita da una figura di Admin / Tecnici; si tratta perlopiù di definizione dei tag e delle CaseMuseo.
Una seconda parte verrà eseguita tendenzialmente da curatori o supporto ai curatori delle singole CaseMuseo; si tratterà di associazioni tra tag e contenuti, o tag e device (casse bt o luci).
Tutte i dati visualizzati e imputati da WUI verranno caricati e salvati su database relazionale. Tutti i JSON di configurazione vanno inseriti nella cartella */home/pi/script/json/* mentre tutti i file video audio delle rispettive sotto cartelle di */home/pi/media/*.

I seguenti esempi sono riferiti tutti alla casa museo con id 2 nel database online.

## Definizione TAG RFID

La definizione dei TAG RFID è il primo step per poter definire il sistema di interazioni. La tabella *tag_uid* con la lista dei tag interattivi.

### Files: rfid.json
*URL:  json.php?m=2&t=rfid*

    [{
	    "id_casamuseo": 1,
	    "rfid": [{
		    "id": 1,
		    "tag_uid": "AE34E1"
	    }, {
		    "id": 2,
		    "tag_uid": "FF540A"
	    }, {
		    "id": 3,
		    "tag_uid": "34567B"
	    }]
    }]

Sarà in questo modo possibile apporre ai TAG rfid una etichetta con ID corrispondente per poterli identificare univocamente e inequivocabilmente.

Imputazione fatta almeno per un primo batch di tag rfid da Admin / Tecnico.

## Definizione contenuti multimediali

I contenuti multimediali (video, audio, chiamate a server MQTT) vanno inseriti nella libreria dei contenuti multimedia.
Da parte del nodo ci sarà una interrogazione al server remoto per ottenere questa tabella, usando come parametro di richiesta l’id della CasaMuseo. La risposta ottenuta, su file multimedia.json sarà formattata come esempio seguente:

### Files: multimedia.json
*URL:  json.php?m=2&t=multimedia*

    [{
	    "id_casamuseo": 1,
	    "multimedia": [{
		    "id": 1,
		    "tipo_media": "video",
		    "descrizione_media": "Video poeta Pascoli",
		    “titolo_media”: “video_pascoli.mp4”,
		    "path_media": "ftp://<ftp_server_remoto>/<path>/video_pascoli.mp4"
	    },{
		    "id": 2,
		    "tipo_media": "audio",
		    "descrizione_media": "Testo poesia Pascoli",
		    “titolo_media”: “audio_pascoli.mp4”,
		    "path_media": "http://<webdav_server_remoto>/<path>/audio_pascoli.mp4"
	    }]

    }]

Sarà in questo modo possibile localmente generare una coda di download per i contenuti, e associarli ad un id univocamente e inequivocabilmente.

### Definizione device: neopixel spot

I neopixel spot vanno inseriti nella libreria dei device.
Da WUI l’utente inserirà l’indirizzo IP di ogni singolo device.
Ci sarà una tabella con di base le informazioni: Id_casa_museo : id : ip_indirizzo

 Da parte del nodo ci sarà una interrogazione al server remoto per ottenere questa tabella, usando come parametro di richiesta l’id della CasaMuseo. La risposta ottenuta, su file neopixelspot.json sarà formattata come esempio seguente:

### File:  neopixelspot.json
*Url:  json.php?m=2&t=neopixelspot*

    [  
       {  
          "id_casamuseo":2,
          "neopixelspot":[  
             {  
                "id":1,
                "description":"Spot 1 luce rossa",
                "ip_indirizzo":"192.168.0.123",
                "colorRGB":"#ff000"
             },
             {  
                "id":2,
                "description":"Spot 2 luce blu",
                "ip_indirizzo":"192.168.0.164",
                "colorRGB":"#0000FF"
             }
          ]
       }
    ]

Imputazione fatta da supporto locale tecnico (è necessario configurare sull’AP degli indirizzi riservati ai neopixelspot).

### Definizione device: speaker bluetooth

Gli speaker bluetooth vanno inseriti nella libreria dei device.
Da WUI l’utente inserirà il mac address del dispositivo BT (ottenuto con uno smartphone scansionando per dispositivi BT) e una descrizione dello stesso.
Ci sarà una tabella con di base le informazioni:
Id_casa_museo : id : bt_mac : bt_descrizione
Da parte del nodo ci sarà una interrogazione al server remoto per ottenere questa tabella, usando come parametro di richiesta l’id della CasaMuseo. La risposta ottenuta, su file bt_speaker.json sarà formattata come esempio seguente:

### File:  bt_speaker.json
*Url:  json.php?m=2&t=bt_speaker*

     [{
    	"id_casamuseo": 1,
    	"bt_speaker": [{
    		"id": 1,
    		"bt_mac": "00:12:23:34:45:56",
    		"bt_descrizione": "Cassa verde grande AUKEY"
    	},{
    		"id": 2,
    		"bt_mac": "98:87:AA:EE:12:DD",
    		"bt_descrizione": "Cassa nera BOSE"
    	}]
    }]

### Definizione device: IKEA TRADFRI

Aggiornamento:

Questa procedura è disattivata la configurazione va fatta da Node-Red. Nello sviluppo futuro si potrà usare questa libreria

[https://github.com/ggravlingen/pytradfri](https://github.com/ggravlingen/pytradfri)  

## Interazione RFID contenuti / devices

La tabella in cui sono registrate le interazioni tra RFID e contenuti e devices è il cuore del sistema. Da WUI l’utente potrà scegliere il tag rfid numerato e associarlo alla cassa bluetooth, piuttosto che ad un video, ad una luce o ad un suono. Ci sarà una tabella con di base le informazioni: Id_casa_museo : id : id_rfid : id_contenuto_device : tipo_contenuto_device
Da parte del nodo ci sarà una interrogazione al server remoto per ottenere questa tabella, usando come parametro di richiesta l’id della CasaMuseo. La risposta ottenuta, su file *interactions.json* sarà formattata come esempio seguente:

### File:  interaction.json
*Url:  json.php?m=2&t=interaction*

      [{
      "id_casamuseo":2,
      "interaction":[{
        "id_rfid":1,
        "object":[{
          "id":1,
          "type":"bt_speaker",
          "id_ix":1
        }]
      },{
        "id_rfid":2,
        "object":[{
          "id":1,
          "type":"multimedia",
          "id_ix":1
        },{
          "id":2,
          "type":"neopixelspot",
          "id_ix":2
      }]
      },{
        "id_rfid":3,
        "object":[{
         L’ho tolto "id":1,
          "type":"bt_speaker",
          "id_ix":1
        },{
          "id":2,
          "type":"multimedia",
          "id_ix":2
        },{
          "id":3,
          "type":"neopixelspot",
          "id_ix":1
        },{
          "id":4,
          "type":"tradfri",
          "id_ix":1
        }]
      }]
    }]

## License

Attribution-NonCommercial 4.0 International (CC BY-NC 4.0)
the  [license](https://creativecommons.org/licenses/by-nc/4.0/legalcode). [Disclaimer](https://creativecommons.org/licenses/by-nc/4.0/#).

Share — copy and redistribute the material in any medium or format
Adapt — remix, transform, and build upon the material
The licensor cannot revoke these freedoms as long as you follow the license terms.
Authors: Mirco Piccin e Michele Zannoni

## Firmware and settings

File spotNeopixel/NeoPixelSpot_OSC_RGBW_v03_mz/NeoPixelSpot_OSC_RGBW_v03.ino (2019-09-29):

/*---------------------------------------------------------------------------------------------
  NeoPixel RGBW Spot v0.3
  M.Piccin 03/2019 for CaseMuseo project
  
  Su D1 R2 & mini board
  Controlled by Open Sound Control (OSC)
  --------------------------------------------------------------------------------------------- */
#ifdef ESP8266
#include <ESP8266WiFi.h>
#else
#include <  >
#endif
#include <WiFiUdp.h>
#include <OSCMessage.h>
#include <OSCBundle.h>
#include <OSCData.h>
#include <Adafruit_NeoPixel.h>

#define PIN            D4
#define NUMPIXELS      16

char ssid[] = "CCM";          // your network SSID (name)
char pass[] = "casamuseo";          // your network password

IPAddress local_IP(192, 168, 1, 44);
IPAddress gateway(192, 168, 1, 1);
IPAddress subnet(255, 255, 255, 0);
IPAddress primaryDNS(8, 8, 8, 8); //optional
IPAddress secondaryDNS(192, 168, 1, 1); //optional

// A UDP instance to let us send and receive packets over UDP
WiFiUDP Udp;
const unsigned int localPort = 8889;        // local port to listen for UDP packets (here's where we send the packets)

Adafruit_NeoPixel pixels = Adafruit_NeoPixel(NUMPIXELS, PIN, NEO_GRBW + NEO_KHZ800);

OSCErrorCode error;

void setup() {
  Serial.begin(115200);

  setup_wifi();

  pixels.begin();
  for (int i = 0; i < NUMPIXELS; i++) {
    pixels.setPixelColor(i, pixels.Color(0, 0, 0, 0));
    pixels.show();
    delay(10);
  }
}


void neopixelspot(OSCMessage &msg) {
  int length = msg.getDataLength(0);
  char msg_str[length];
  msg.getString(0, msg_str, length);

  byte redval   = fromhex (& msg_str [1]);
  byte greenval = fromhex (& msg_str [3]);
  byte blueval  = fromhex (& msg_str [5]);
  byte whiteval = fromhex (& msg_str [7]);

  /*
    Serial.print(msg_str);
    Serial.print("-");
    Serial.print(redval);
    Serial.print("-");
    Serial.print(greenval);
    Serial.print("-");
    Serial.print(blueval);
    Serial.print("-");
    Serial.println(whiteval);
  */

  for (int i = 0; i < NUMPIXELS; i++) {
    pixels.setPixelColor(i, pixels.Color((int) redval, (int) greenval,  (int) blueval,  (int) whiteval));
    pixels.show();
    delay(10);
  }

}

void loop() {
  OSCMessage msg;
  int size = Udp.parsePacket();

  if (size > 0) {
    while (size--) {
      msg.fill(Udp.read());
    }
    if (!msg.hasError()) {
      msg.dispatch("/neopixelspot", neopixelspot);
    } else {
      error = msg.getError();
      Serial.print("error: ");
      Serial.println(error);
    }
  }
}

void setup_wifi() {

  delay(10);

  //clean up AP mode and force STA mode
  //https://stackoverflow.com/questions/39688410/how-to-switch-to-normal-wifi-mode-to-access-point-mode-esp8266
  WiFi.softAPdisconnect();
  WiFi.disconnect();
  WiFi.mode(WIFI_STA);
  delay(100);

  // We start by connecting to a WiFi network
  Serial.println();
  Serial.print("Connecting to ");
  Serial.println(ssid);

  if (!WiFi.config(local_IP, gateway, subnet, primaryDNS, secondaryDNS)) {
    Serial.println("STA Failed to configure");
  }

  WiFi.begin(ssid, pass);

  while (WiFi.status() != WL_CONNECTED) {
    delay(500);
    Serial.print(".");
  }

  Serial.println("");
  Serial.println("WiFi connected");
  Serial.println("IP address: ");
  Serial.println(WiFi.localIP());

  Serial.println("Starting UDP");
  Udp.begin(localPort);
}


byte fromhex (const char * str) {
  char c = str [0] - '0';
  if (c > 9) {
    c -= 7;
  }
  int result = c;
  c = str [1] - '0';
  if (c > 9) {
    c -= 7;
  }
  return (result << 4) | c;
}

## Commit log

2019-09-29 3d files
    [Reader_base_button_05a.stl, Reader_battery_05d.stl, Reader_bottom_head_05d.stl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]
2019-10-06 Upgrade
    Reader New Flow V08
    Reader Changing logo
    Server PHP new device manager V08 compatible
